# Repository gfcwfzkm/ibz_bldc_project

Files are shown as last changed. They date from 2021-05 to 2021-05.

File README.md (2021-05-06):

# ibz_bldc_project
A group project I participated in during my time in the IBZ side school. The task was any electronic project, so three other fellow students and I decided to build a BLDC driver.
I took care of the schematic, components and layout, another one handled assembly & basic testing, one did the programming / controlling and the last documented the whole project.
This project is not maintained but more a rough reference if anyone else wants to build something similar.
It uses the L6234 as BLDC driver and offers either HALL-Sensor Input or Back-EMF (selectable via jumpers) as well as enough test points to probe on. It was laid out to be a rather flexible but basic platform to explore BLDC Motor driving a bit more.

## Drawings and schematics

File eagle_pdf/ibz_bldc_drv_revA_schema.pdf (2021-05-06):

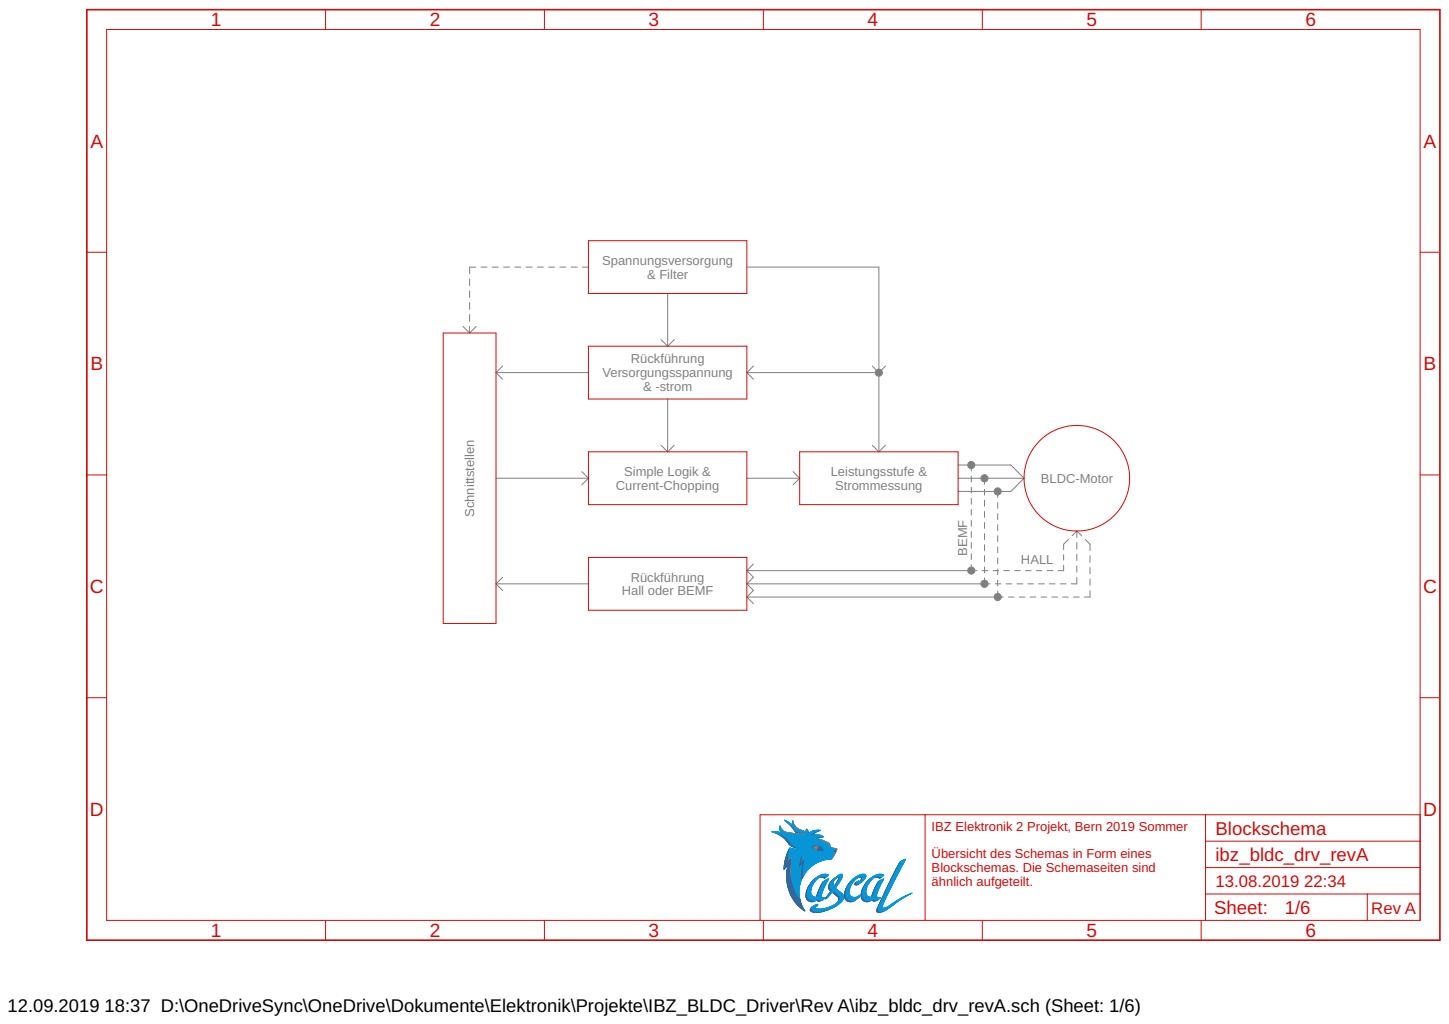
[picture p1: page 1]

IBZ Elektronik 2 Projekt, Bern 2019 Sommer Übersicht des Schemas in Form eines Blockschemas. Die Schemaseiten sind

12.09.2019 18:37 D:\OneDriveSync\OneDrive\Dokumente\Elektronik\Projekte\IBZ_BLDC_Driver\Rev A\ibz_bldc_drv_revA.sch (Sheet: 1/6)

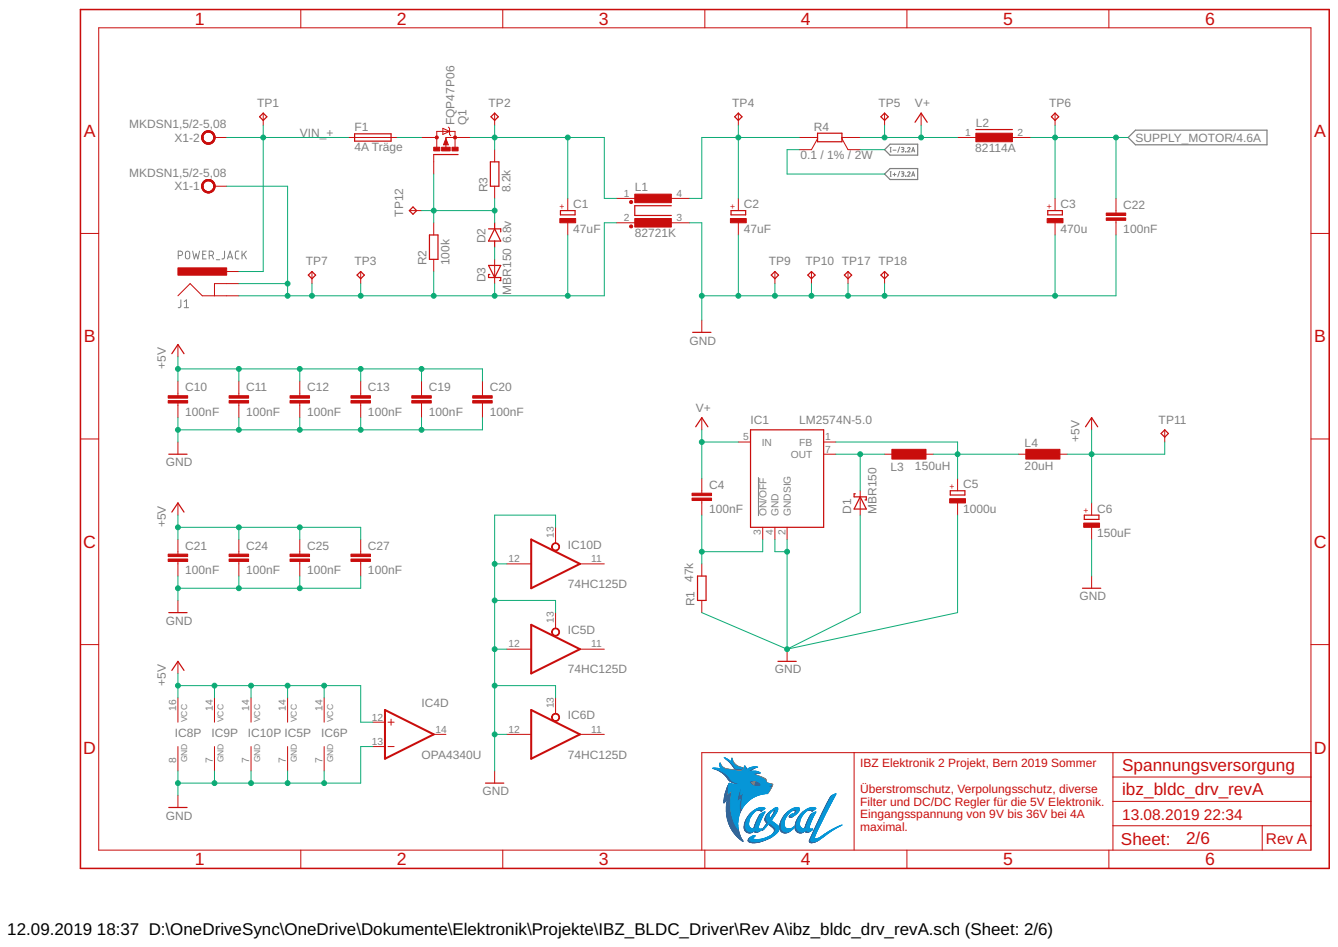
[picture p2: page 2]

12.09.2019 18:37 D:\OneDriveSync\OneDrive\Dokumente\Elektronik\Projekte\IBZ_BLDC_Driver\Rev A\ibz_bldc_drv_revA.sch (Sheet: 2/6)

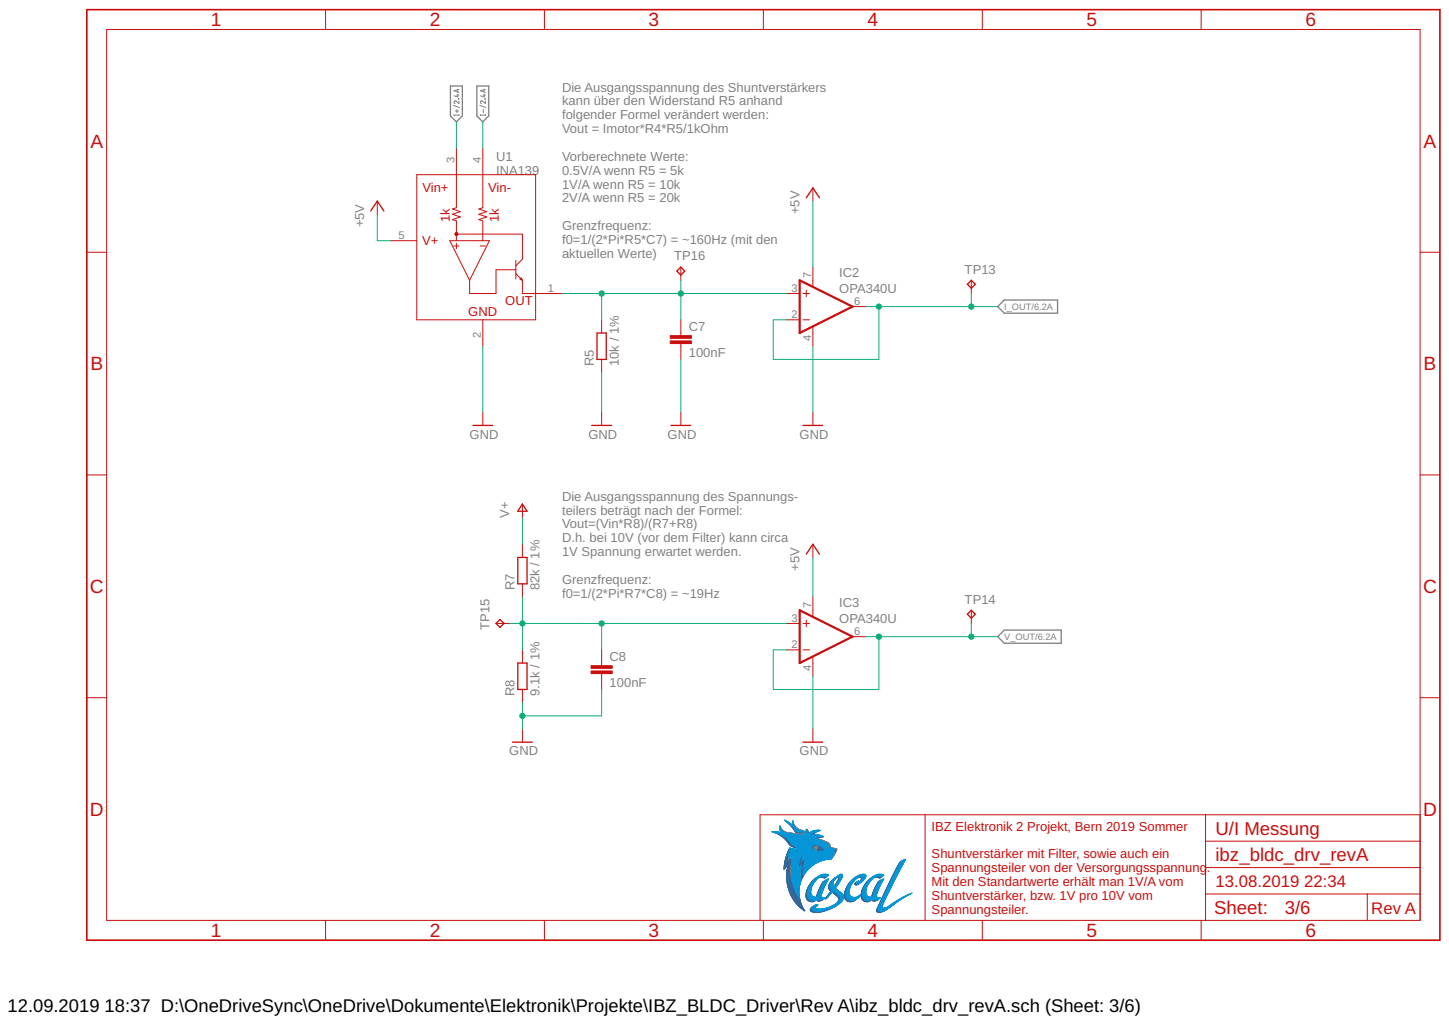
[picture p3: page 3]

Die Ausgangsspannung des Shuntverstärkers
kann über den Widerstand R5 anhand
folgender Formel verändert werden: Vout = Imotor*R4*R5/1kOhm

Die Ausgangsspannung des Spannungs-
teilers beträgt nach der Formel: Vout=(Vin*R8)/(R7+R8)

D.h. bei 10V (vor dem Filter) kann circa
1V Spannung erwartet werden. Grenzfrequenz:

IBZ Elektronik 2 Projekt, Bern 2019 Sommer Shuntverstärker mit Filter, sowie auch ein Spannungsteiler von der Versorgungsspannung. Mit den Standartwerte erhält man 1V/A vom

Shuntverstärker, bzw. 1V pro 10V vom

12.09.2019 18:37 D:\OneDriveSync\OneDrive\Dokumente\Elektronik\Projekte\IBZ_BLDC_Driver\Rev A\ibz_bldc_drv_revA.sch (Sheet: 3/6)

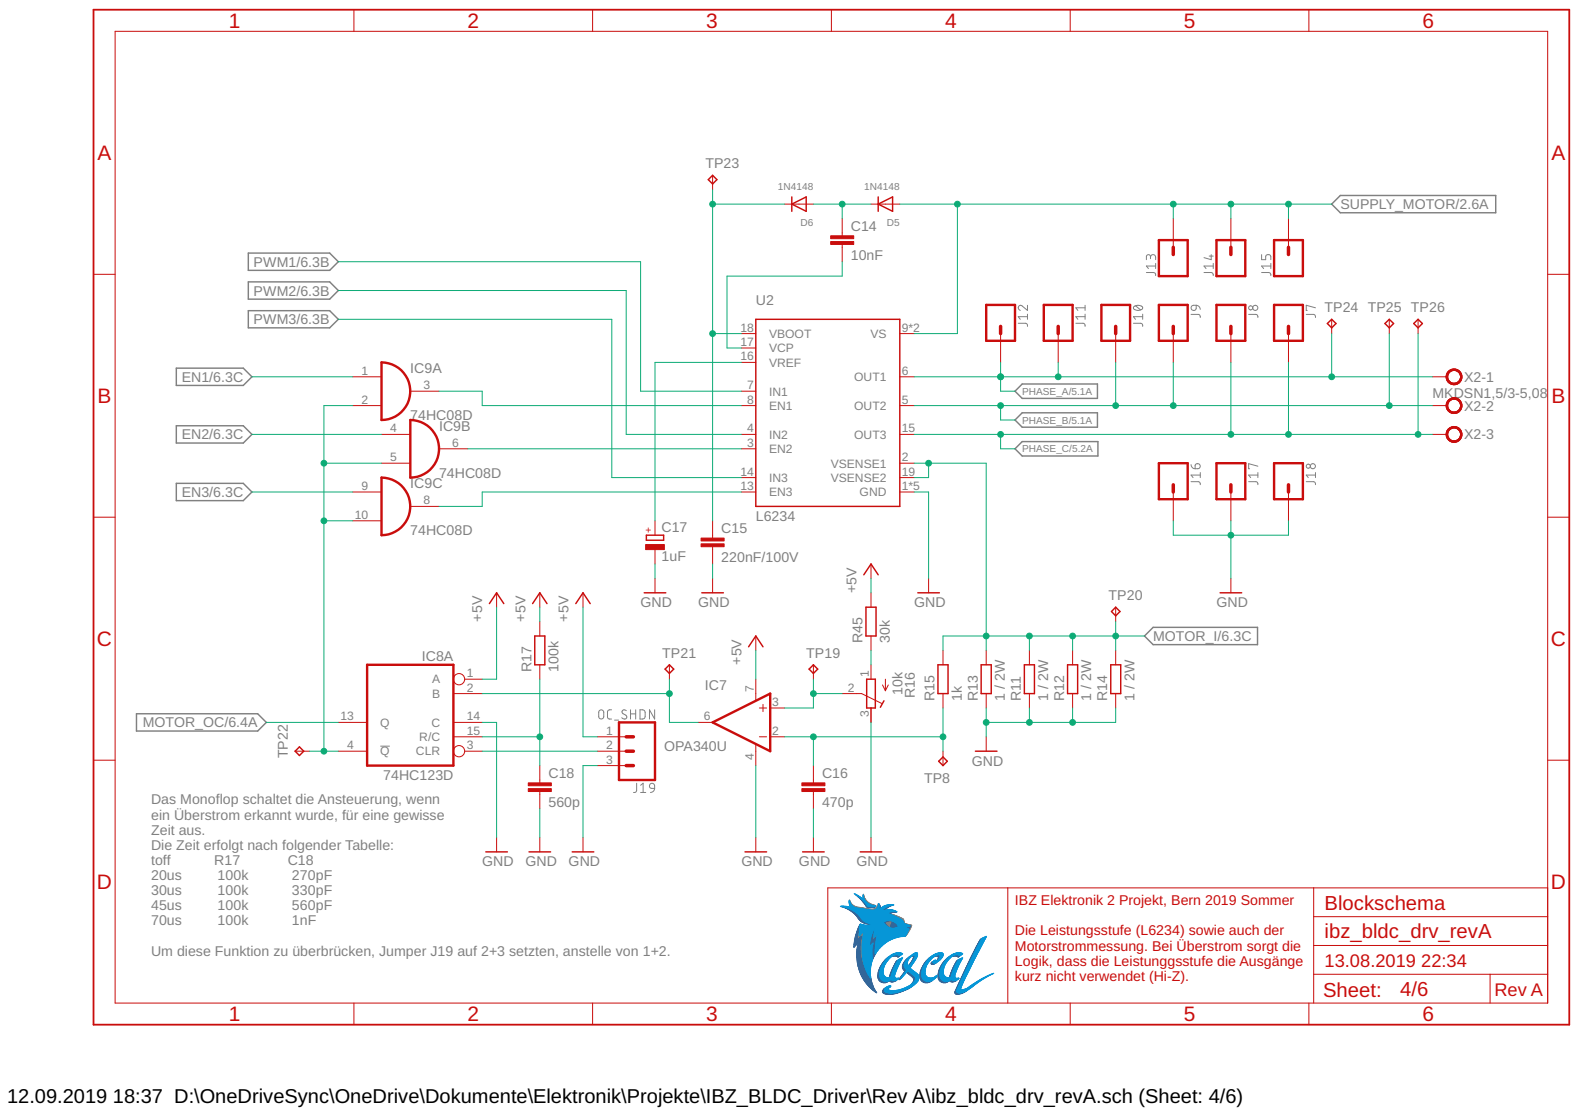
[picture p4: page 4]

Das Monoflop schaltet die Ansteuerung, wenn
ein Überstrom erkannt wurde, für eine gewisse Zeit aus. Die Zeit erfolgt nach folgender Tabelle:

IBZ Elektronik 2 Projekt, Bern 2019 Sommer Die Leistungsstufe (L6234) sowie auch der Motorstrommessung. Bei Überstrom sorgt die

Um diese Funktion zu überbrücken, Jumper J19 auf 2+3 setzten, anstelle von 1+2.

Logik, dass die Leistunggsstufe die Ausgänge

12.09.2019 18:37 D:\OneDriveSync\OneDrive\Dokumente\Elektronik\Projekte\IBZ_BLDC_Driver\Rev A\ibz_bldc_drv_revA.sch (Sheet: 4/6)

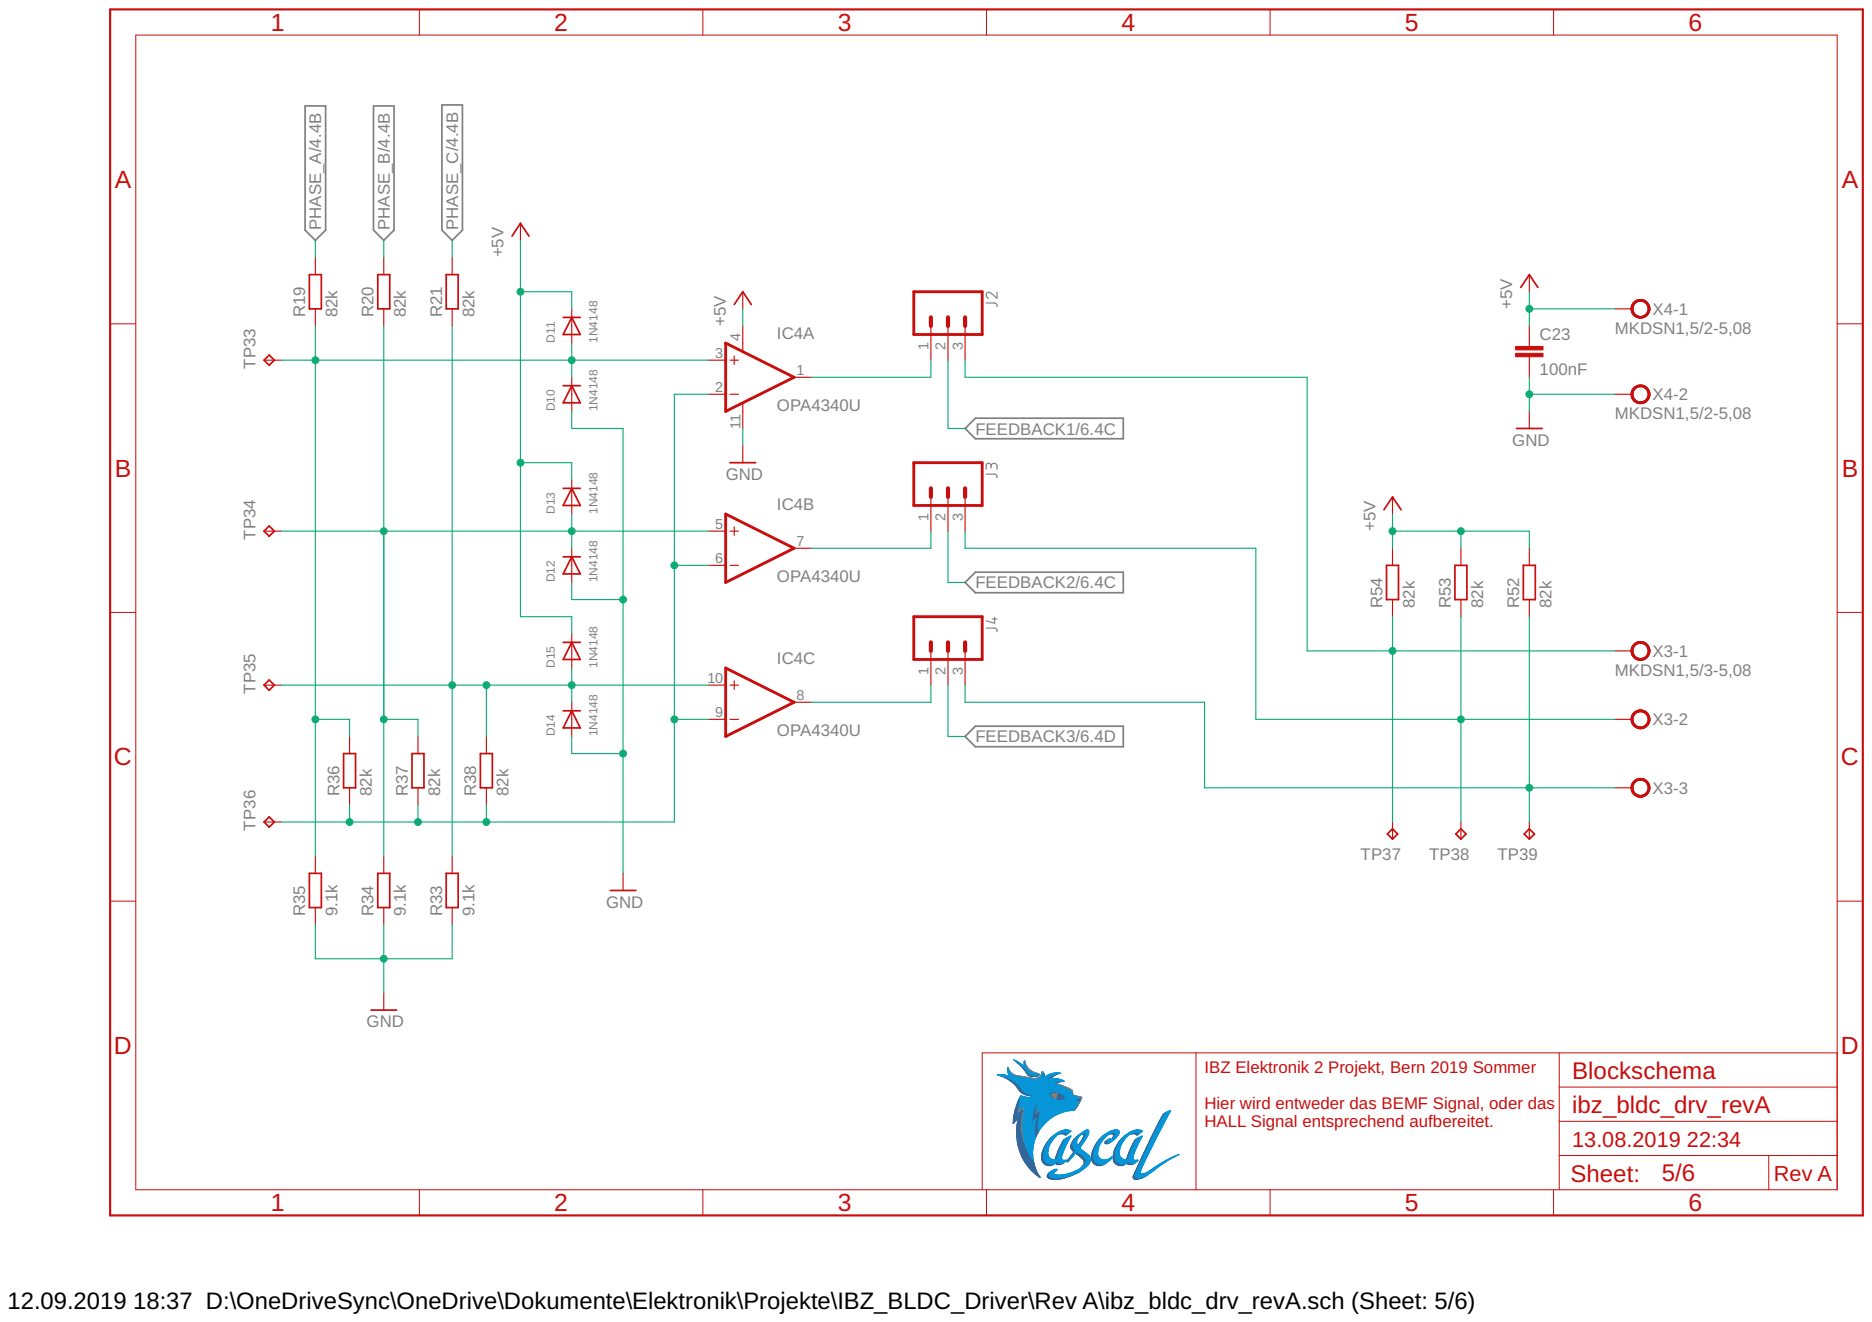
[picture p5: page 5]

12.09.2019 18:37 D:\OneDriveSync\OneDrive\Dokumente\Elektronik\Projekte\IBZ_BLDC_Driver\Rev A\ibz_bldc_drv_revA.sch (Sheet: 5/6)

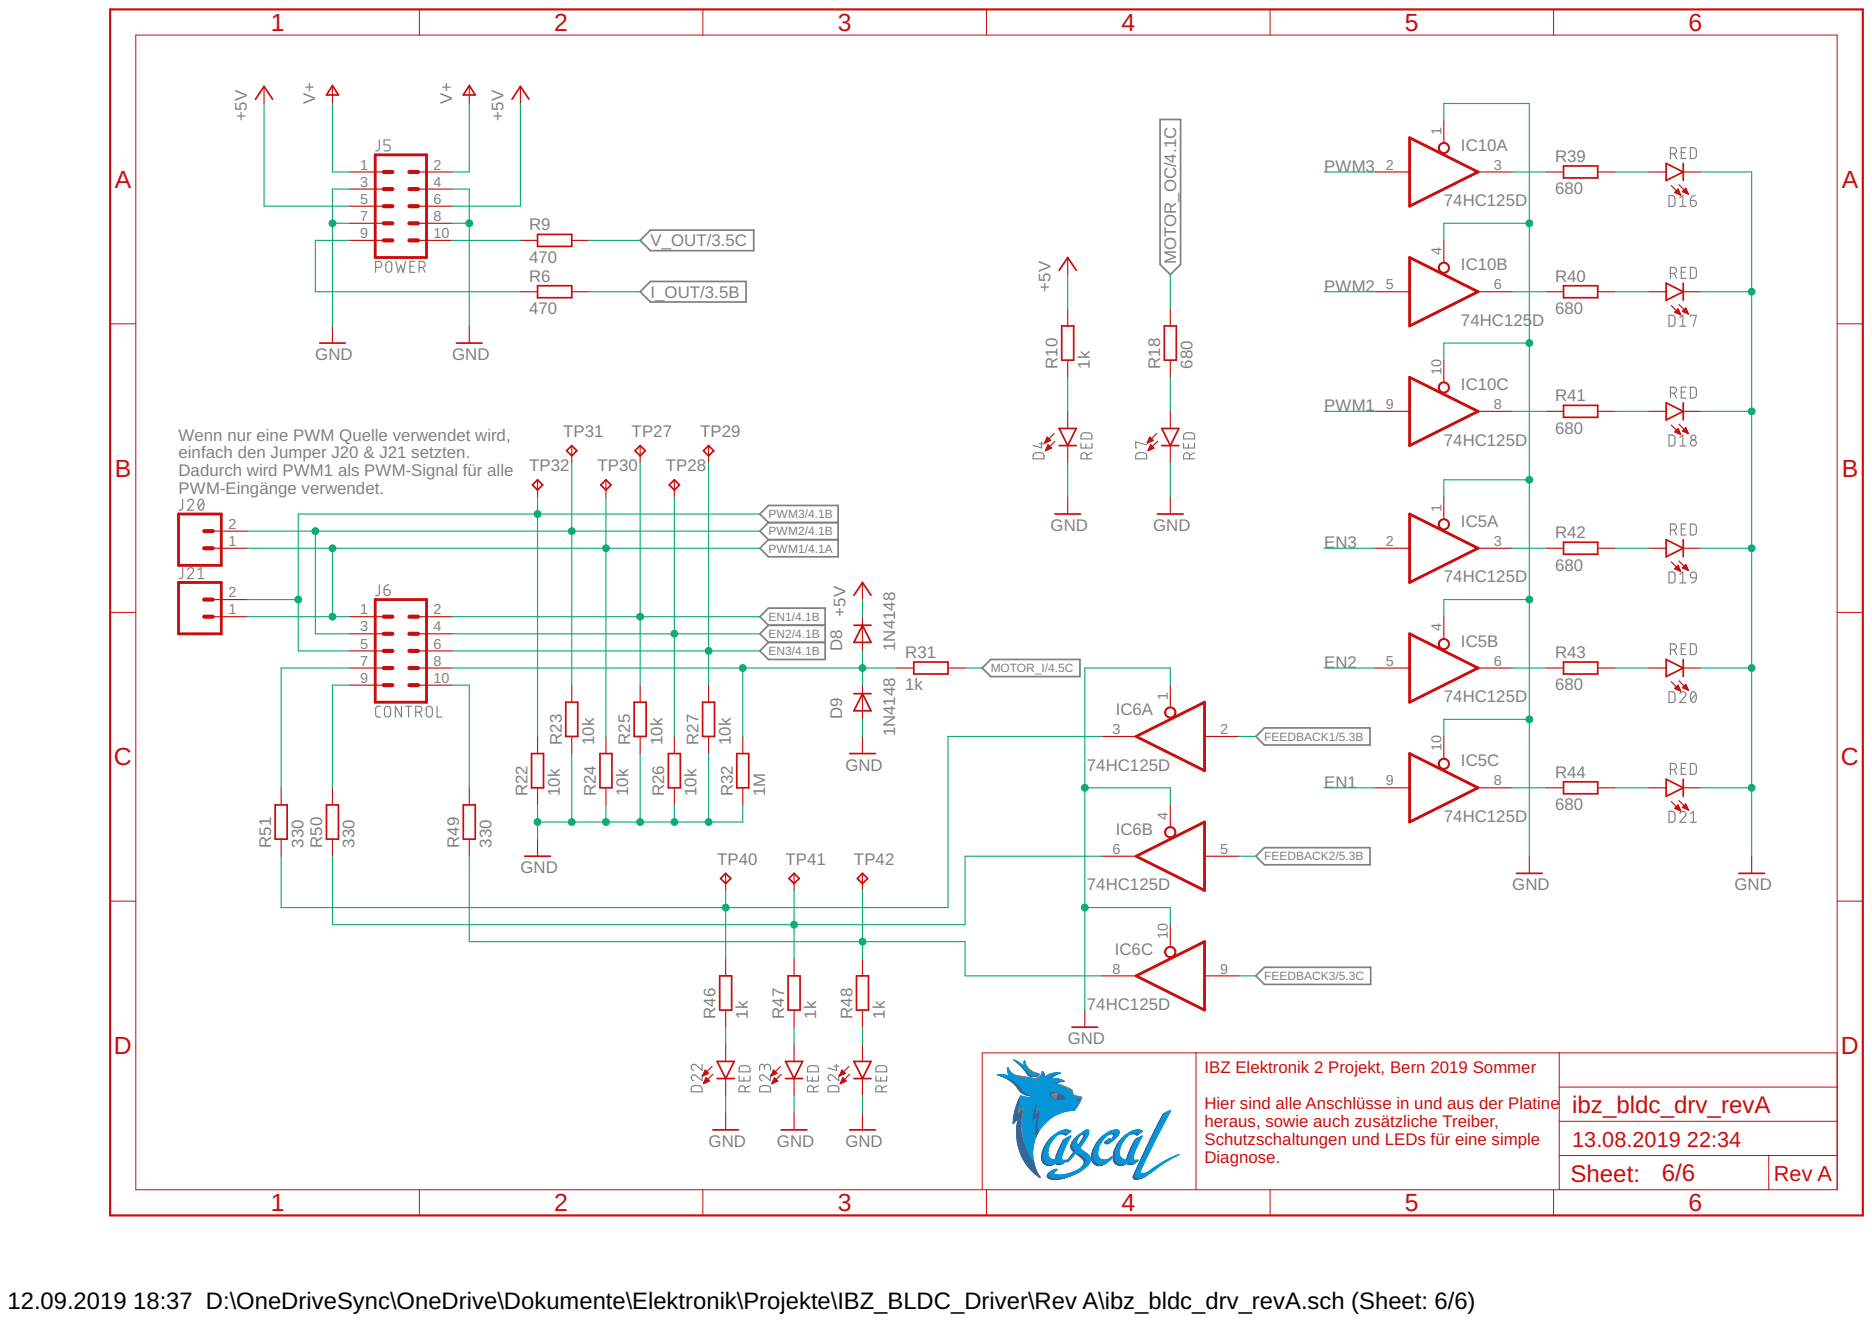
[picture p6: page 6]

Wenn nur eine PWM Quelle verwendet wird, einfach den Jumper J20 & J21 setzten. Dadurch wird PWM1 als PWM-Signal für alle PWM-Eingänge verwendet.

10

IBZ Elektronik 2 Projekt, Bern 2019 Sommer Hier sind alle Anschlüsse in und aus der Platine

12.09.2019 18:37 D:\OneDriveSync\OneDrive\Dokumente\Elektronik\Projekte\IBZ_BLDC_Driver\Rev A\ibz_bldc_drv_revA.sch (Sheet: 6/6)

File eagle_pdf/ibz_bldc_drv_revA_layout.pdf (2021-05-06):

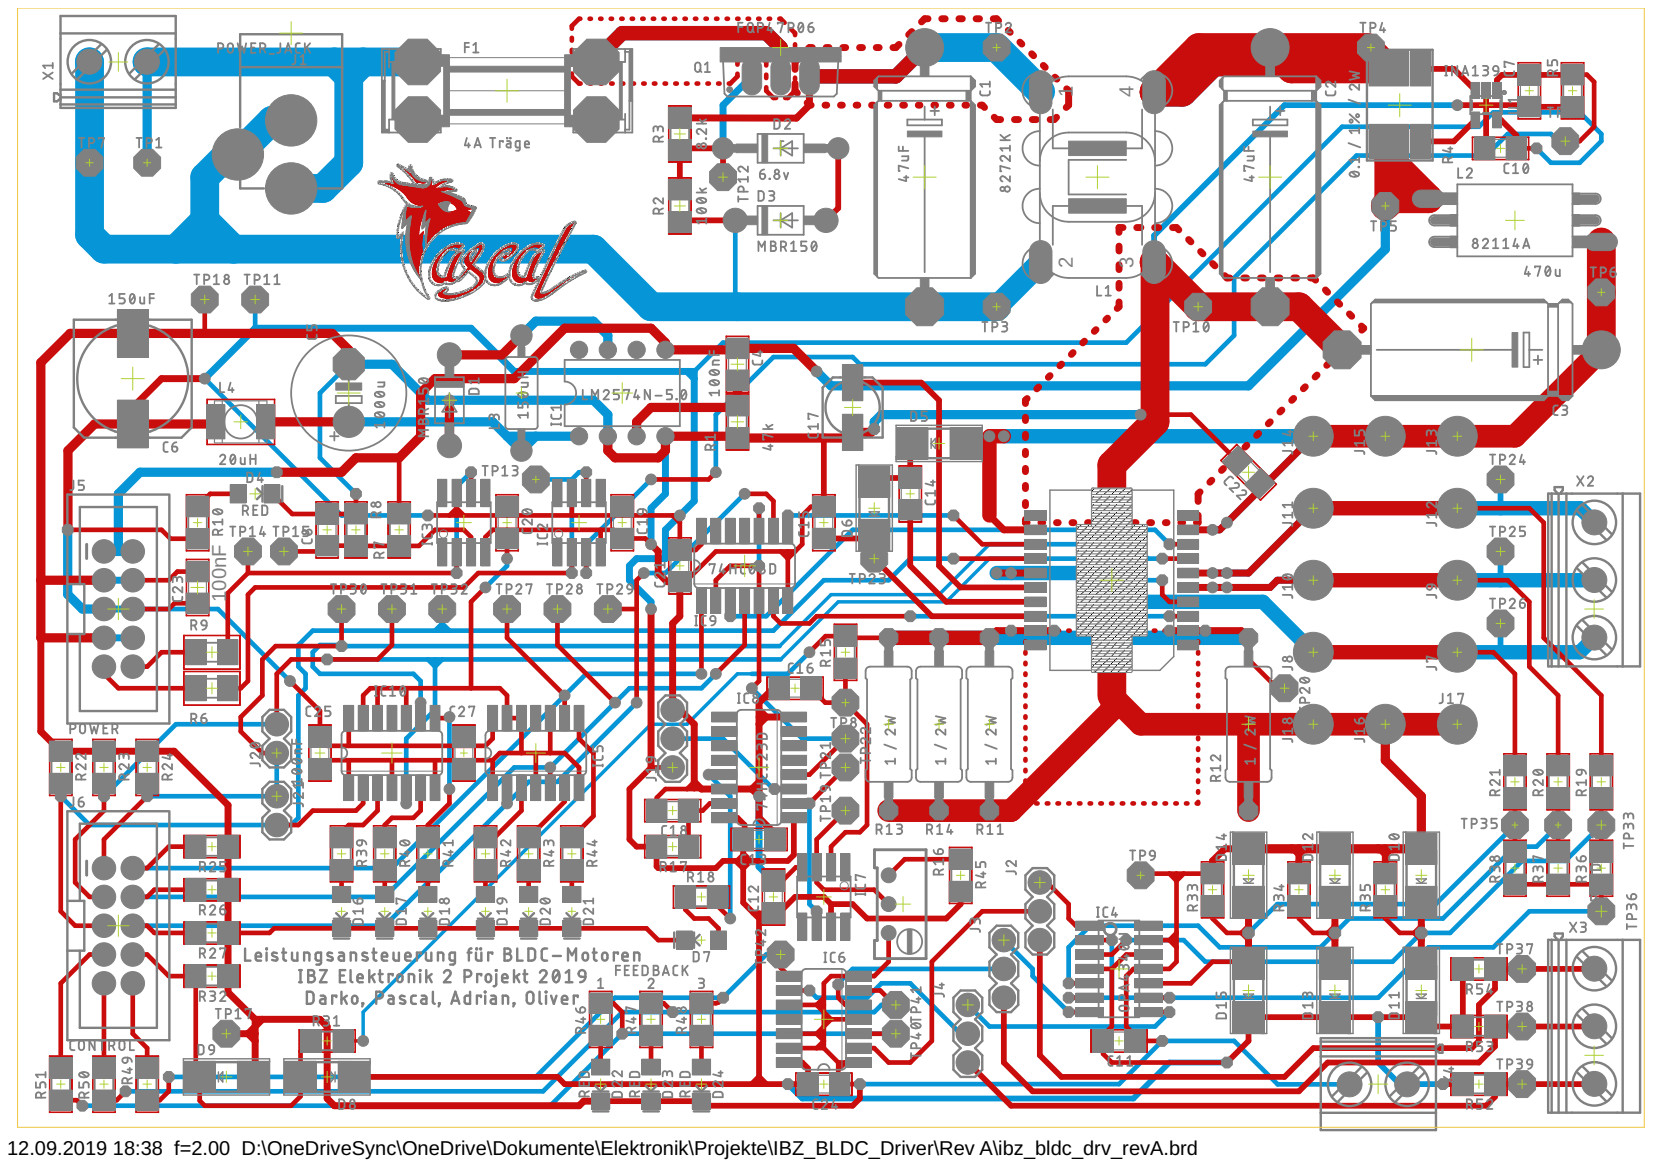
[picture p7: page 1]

12.09.2019 18:38 f=2.00 D:\OneDriveSync\OneDrive\Dokumente\Elektronik\Projekte\IBZ_BLDC_Driver\Rev A\ibz_bldc_drv_revA.brd

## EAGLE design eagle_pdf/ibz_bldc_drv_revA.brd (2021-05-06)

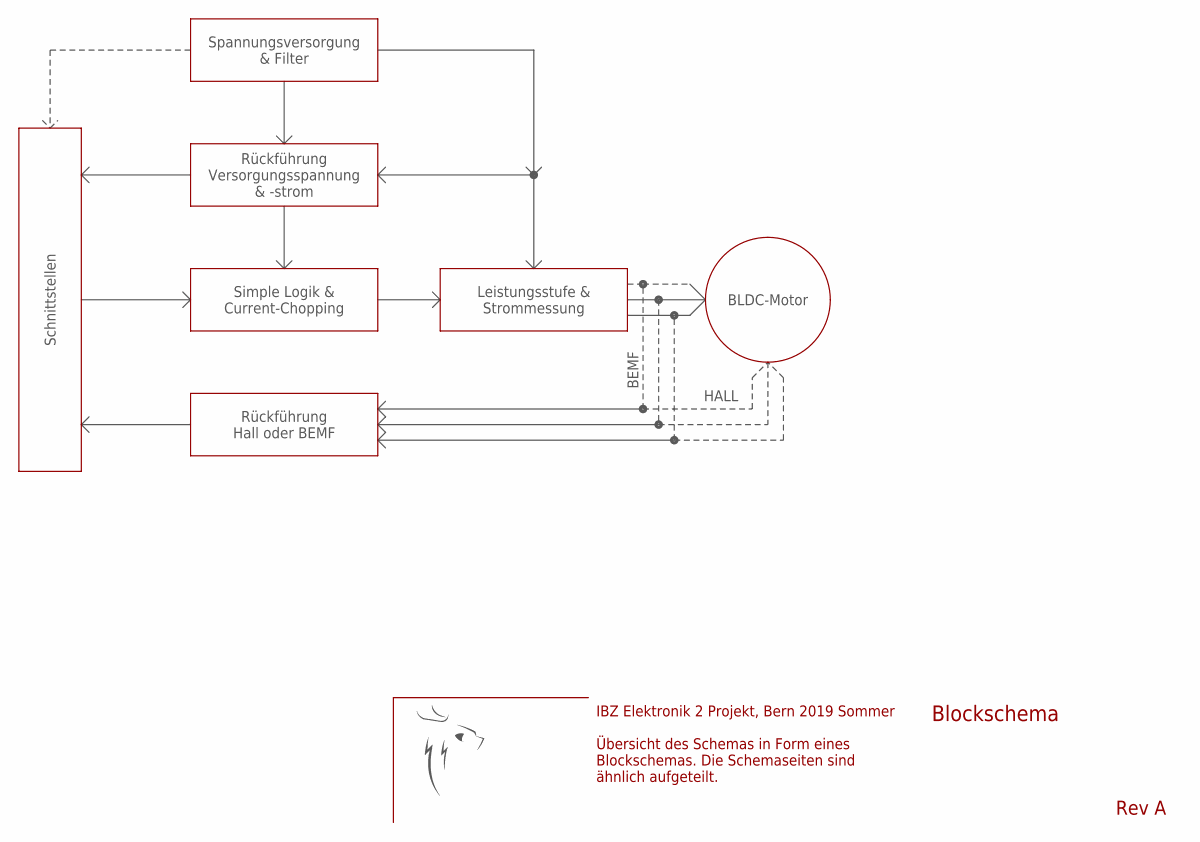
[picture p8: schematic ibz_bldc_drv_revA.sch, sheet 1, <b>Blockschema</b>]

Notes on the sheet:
Spannungsversorgung & Filter
BLDC-Motor
Leistungsstufe & Strommessung
Simple Logik & Current-Chopping
Schnittstellen
Rückführung Versorgungsspannung & -strom
Rückführung Hall oder BEMF
BEMF
HALL
Blockschema
Rev A
IBZ Elektronik 2 Projekt, Bern 2019 Sommer Übersicht des Schemas in Form eines Blockschemas. Die Schemaseiten sind ähnlich aufgeteilt.

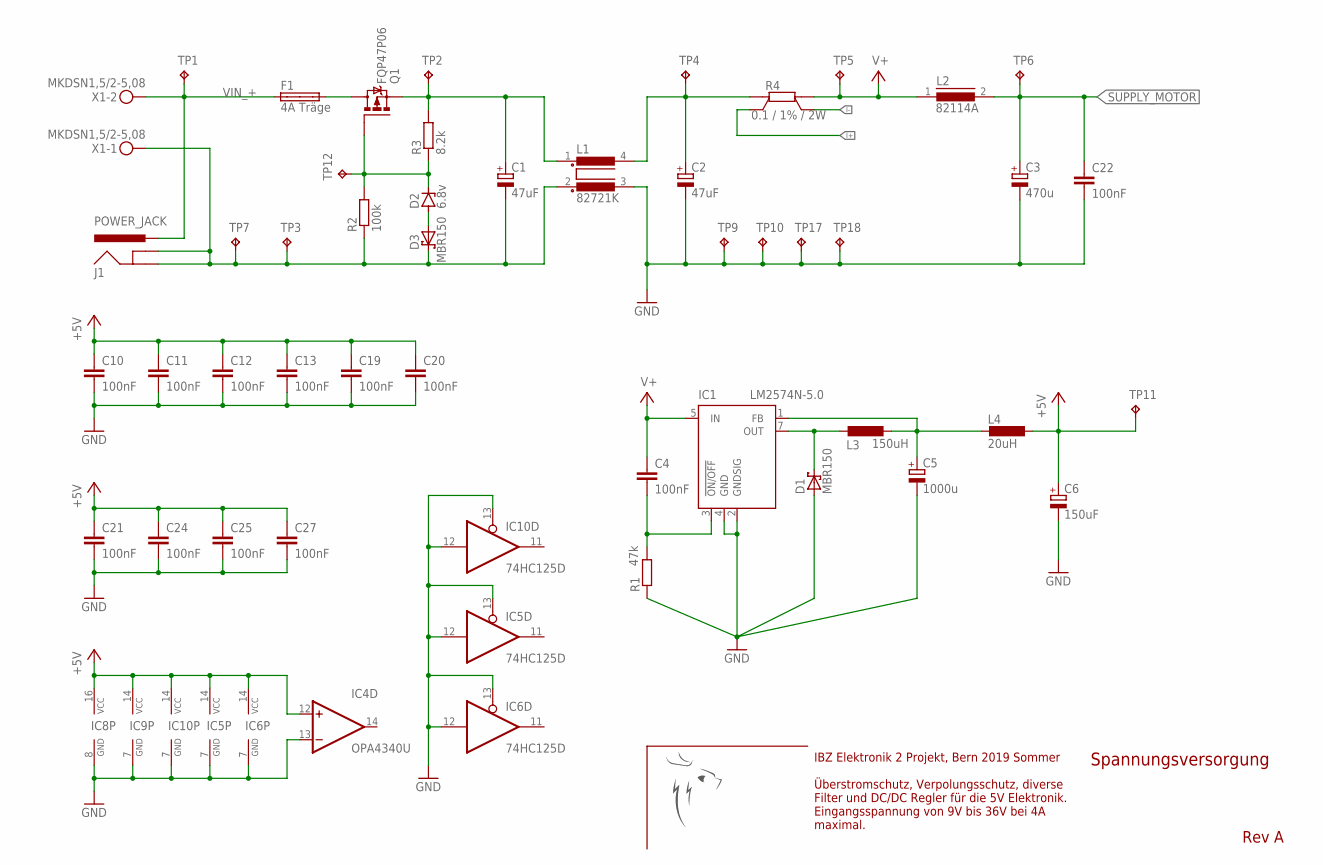
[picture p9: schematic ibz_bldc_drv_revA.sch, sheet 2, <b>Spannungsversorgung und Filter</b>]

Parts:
C1, C2: 47uF; E22-9
C3: 470u; E22-9
C4, C10, C11, C12, C13, C19, C20, C21, C22, C24, C25, C27: 100nF; C1206
C5: 1000u; E5-10,5
C6: 150uF; 153CLV-1010
D1, D3: MBR150; DO41-7
D2: 6.8v; DO41Z10
F1: 4A Träge; SHK20Q
IC1: LM2574N-5.0; DIL08
IC4: OPA4340U; SO14
IC5, IC6, IC10: 74HC125D; SO14
IC8: 74HC123D; SO16
IC9: 74HC08D; SO14
J1: POWER_JACK; POWER_JACK_PTH
L1: 82721K
L2: 82114A
L3: 150uH; IR-2
L4: 20uH; L5038P
Q1: FQP47P06; TO220BV
R1: 47k; R1206
R2: 100k; R1206
R3: 8.2k; R1206
R4: 0.1 / 1% / 2W; PMA-B
TP1, TP2, TP3, TP4, TP5, TP6, TP7, TP9, TP10, TP11, TP12, TP17, TP18: TPPAD1-13; P1-13
X1: MKDSN1,5/2-5,08

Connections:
+5V: C6.+, C10.1, C11.1, C12.1, C13.1, C19.1, C20.1, C21.1, C24.1, C25.1, C27.1, IC4.12 (+IN), IC5.14 (VCC), IC6.14 (VCC), IC8.16 (VCC), IC9.14 (VCC), IC10.14 (VCC), L4.1, TP11.TP; also elsewhere on the board
GND: C2.-, C3.-, C5.-, C6.-, C10.2, C11.2, C12.2, C13.2, C19.2, C20.2, C21.2, C22.2, C24.2, C25.2, C27.2, D1.A, IC1.2 (GNDSIG), IC1.4 (GND), IC4.13 (-IN), IC5.7 (GND), IC5.12 (I), IC5.13 (OE), IC6.7 (GND), IC6.12 (I), IC6.13 (OE), IC8.8 (GND), IC9.7 (GND), IC10.7 (GND), IC10.12 (I), IC10.13 (OE), L1.3 (4), R1.1, TP9.TP, TP10.TP, TP17.TP, TP18.TP; also elsewhere on the board
I+: R4.SB; also elsewhere on the board
I-: R4.SA; also elsewhere on the board
unnamed: C1.-, D3.C, J1.GND, J1.GNDBREAK, L1.2 (3), R2.1, TP3.TP, TP7.TP, X1.1
unnamed: C1.+, L1.1, Q1.S, R3.2, TP2.TP
unnamed: C2.+, L1.4 (2), R4.B, TP4.TP
unnamed: C4.2, IC1.3 (!ON/OFF), R1.2
unnamed: C5.+, IC1.1 (FB), L3.1, L4.2
unnamed: D1.C, IC1.7 (OUT), L3.2
unnamed: F1.2A, Q1.D
unnamed: D2.C, Q1.G, R2.2, R3.1, TP12.TP
unnamed: D2.A, D3.A
SUPPLY_MOTOR: C3.+, C22.1, L2.2, TP6.TP; also elsewhere on the board
V+: C4.1, IC1.5 (IN), L2.1, R4.A, TP5.TP; also elsewhere on the board
VIN_+: F1.1A, J1.PWR, TP1.TP, X1.2

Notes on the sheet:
IBZ Elektronik 2 Projekt, Bern 2019 Sommer Überstromschutz, Verpolungsschutz, diverse Filter und DC/DC Regler für die 5V Elektronik. Eingangsspannung von 9V bis 36V bei 4A maximal.
Spannungsversorgung
Rev A

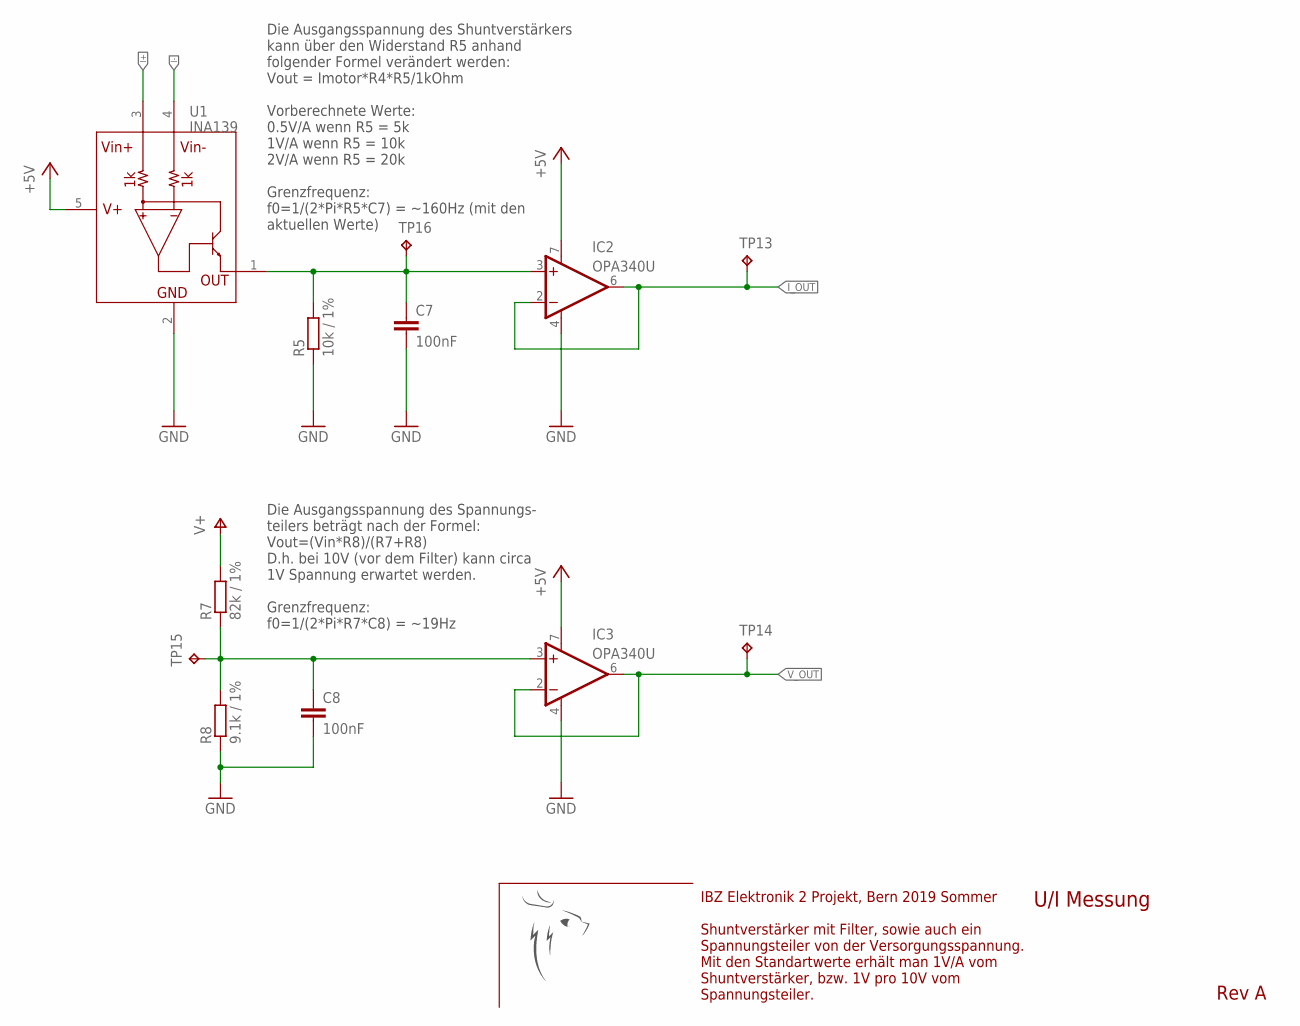
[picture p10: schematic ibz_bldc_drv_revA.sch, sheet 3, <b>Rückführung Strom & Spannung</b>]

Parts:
C7, C8: 100nF; C1206
IC2, IC3: OPA340U; SO08
R5: 10k / 1%; R1206
R7: 82k / 1%; R1206
R8: 9.1k / 1%; R1206
TP13, TP14, TP15, TP16: TPPAD1-13; P1-13
U1: INA139; SOT23-5

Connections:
+5V: IC2.7 (V+), IC3.7 (V+), U1.5 (V+); also elsewhere on the board
GND: C7.2, C8.2, IC2.4 (V-), IC3.4 (V-), R5.1, R8.1, U1.2 (GND); also elsewhere on the board
I+: U1.3 (VIN+); also elsewhere on the board
I-: U1.4 (VIN-); also elsewhere on the board
I_OUT: IC2.2 (-IN), IC2.6 (OUT), TP13.TP; also elsewhere on the board
unnamed: C7.1, IC2.3 (+IN), R5.2, TP16.TP, U1.1 (OUT)
unnamed: C8.1, IC3.3 (+IN), R7.1, R8.2, TP15.TP
V+: R7.2; also elsewhere on the board
V_OUT: IC3.2 (-IN), IC3.6 (OUT), TP14.TP; also elsewhere on the board

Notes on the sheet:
Die Ausgangsspannung des Shuntverstärkers kann über den Widerstand R5 anhand folgender Formel verändert werden: Vout = Imotor*R4*R5/1kOhm Vorberechnete Werte: 0.5V/A wenn R5 = 5k 1V/A wenn R5 = 10k 2V/A wenn R5 = 20k Grenzfrequenz: f0=1/(2*Pi*R5*C7) = ~160Hz (mit den aktuellen Werte)
Die Ausgangsspannung des Spannungs- teilers beträgt nach der Formel: Vout=(Vin*R8)/(R7+R8) D.h. bei 10V (vor dem Filter) kann circa 1V Spannung erwartet werden. Grenzfrequenz: f0=1/(2*Pi*R7*C8) = ~19Hz
IBZ Elektronik 2 Projekt, Bern 2019 Sommer Shuntverstärker mit Filter, sowie auch ein Spannungsteiler von der Versorgungsspannung. Mit den Standartwerte erhält man 1V/A vom Shuntverstärker, bzw. 1V pro 10V vom Spannungsteiler.
U/I Messung
Rev A

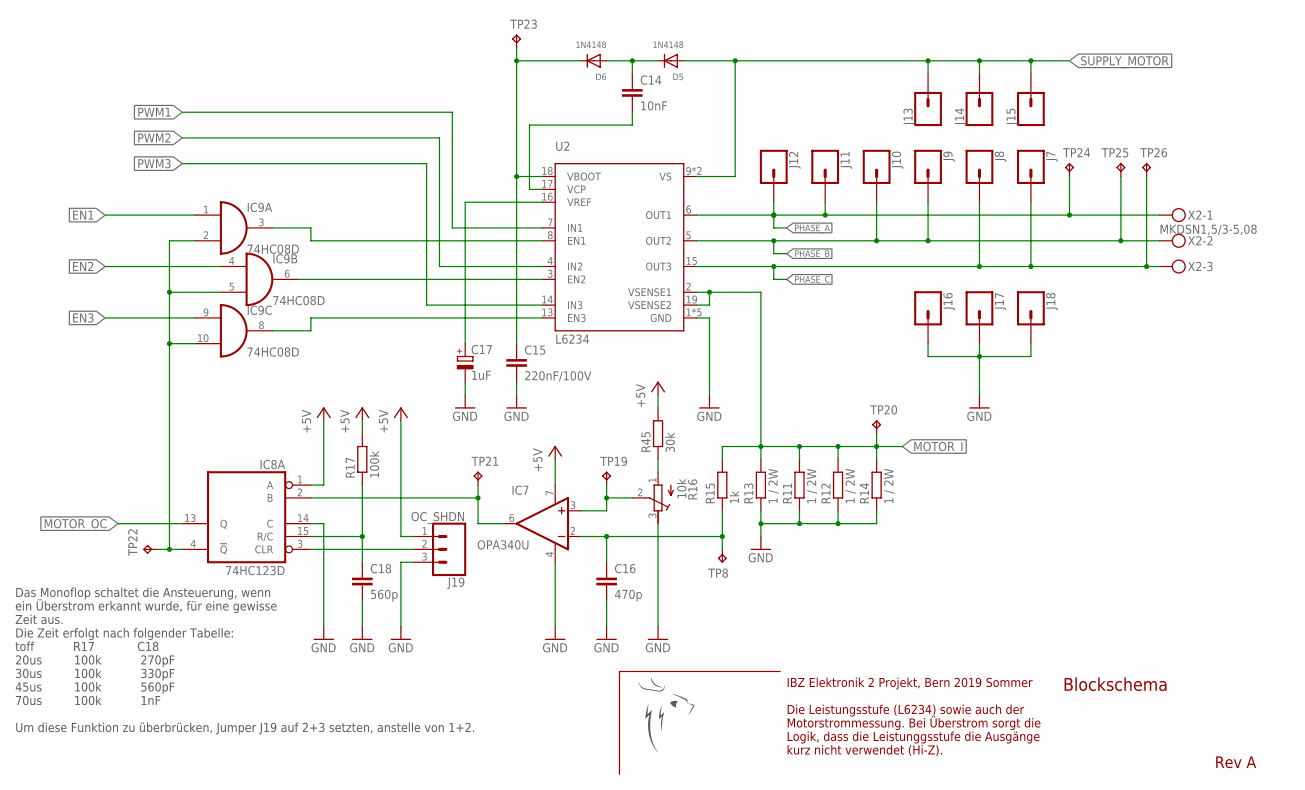
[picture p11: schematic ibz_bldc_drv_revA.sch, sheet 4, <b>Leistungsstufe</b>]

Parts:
C14: 10nF; C1206
C15: 220nF/100V; C1206
C16: 470p; C1206
C17: 1uF; 153CLV-0505
C18: 560p; C1206
D5, D6: 1N4148; SMADIODE
IC7: OPA340U; SO08
IC8: 74HC123D; SO16
IC9: 74HC08D; SO14
J7, J8, J9, J10, J11, J12, J13, J14, J15, J16, J17, J18: CONN_01PTH_2MM; 1X01_2MM
J19: OC_SHDN; 1X03
R11, R12, R13, R14: 1 / 2W; 0411/15
R15: 1k; R1206
R16: 10k; RTRIM64W
R17: 100k; R1206
R45: 30k; R1206
TP8, TP19, TP20, TP21, TP22, TP23, TP24, TP25, TP26: TPPAD1-13; P1-13
U2: L6234; POWERSO20
X2: MKDSN1,5/3-5,08

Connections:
+5V: IC7.7 (V+), IC8.1 (A), J19.1, R17.2, R45.2; also elsewhere on the board
EN1: IC9.1 (I0); also elsewhere on the board
EN2: IC9.4 (I0); also elsewhere on the board
EN3: IC9.9 (I0); also elsewhere on the board
GND: C15.2, C16.2, C17.-, C18.2, IC7.4 (V-), IC8.14 (C), J16.1, J17.1, J18.1, J19.3, R11.1, R12.1, R13.1, R14.1, R16.3 (E), U2.1 (GND), U2.10 (GND), U2.11 (GND), U2.20 (GND), U2.PAD (GND); also elsewhere on the board
MOTOR_I: R11.2, R12.2, R13.2, R14.2, R15.2, TP20.TP, U2.2 (VSENSE1), U2.19 (VSENSE2); also elsewhere on the board
MOTOR_OC: IC8.13 (Q); also elsewhere on the board
unnamed: C14.1, D5.C, D6.A
unnamed: IC9.3 (O), U2.8 (EN1)
unnamed: C15.1, D6.C, TP23.TP, U2.18 (VBOOT)
unnamed: C14.2, U2.17 (VCP)
unnamed: C17.+, U2.16 (VREF)
unnamed: IC9.6 (O), U2.3 (EN2)
unnamed: IC9.8 (O), U2.13 (EN3)
unnamed: C16.1, IC7.2 (-IN), R15.1, TP8.TP
unnamed: IC8.4 (!Q), IC9.2 (I1), IC9.5 (I1), IC9.10 (I1), TP22.TP
unnamed: IC7.6 (OUT), IC8.2 (B), TP21.TP
unnamed: C18.1, IC8.15 (R/C), R17.1
unnamed: IC8.3 (CLR), J19.2
unnamed: IC7.3 (+IN), R16.2 (S), TP19.TP
unnamed: R16.1 (A), R45.1
PHASE_A: J11.1, J12.1, TP24.TP, U2.6 (OUT1), X2.1; also elsewhere on the board
PHASE_B: J9.1, J10.1, TP25.TP, U2.5 (OUT2), X2.2; also elsewhere on the board
PHASE_C: J7.1, J8.1, TP26.TP, U2.15 (OUT3), X2.3; also elsewhere on the board
PWM1: U2.7 (IN1); also elsewhere on the board
PWM2: U2.4 (IN2); also elsewhere on the board
PWM3: U2.14 (IN3); also elsewhere on the board
SUPPLY_MOTOR: D5.A, J13.1, J14.1, J15.1, U2.9 (VS), U2.12 (VS); also elsewhere on the board

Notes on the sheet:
IBZ Elektronik 2 Projekt, Bern 2019 Sommer Die Leistungsstufe (L6234) sowie auch der Motorstrommessung. Bei Überstrom sorgt die Logik, dass die Leistunggsstufe die Ausgänge kurz nicht verwendet (Hi-Z).
Blockschema
Rev A
Das Monoflop schaltet die Ansteuerung, wenn ein Überstrom erkannt wurde, für eine gewisse Zeit aus. Die Zeit erfolgt nach folgender Tabelle: toff R17 C18 20us 100k 270pF 30us 100k 330pF 45us 100k 560pF 70us 100k 1nF Um diese Funktion zu überbrücken, Jumper J19 auf 2+3 setzten, anstelle von 1+2.

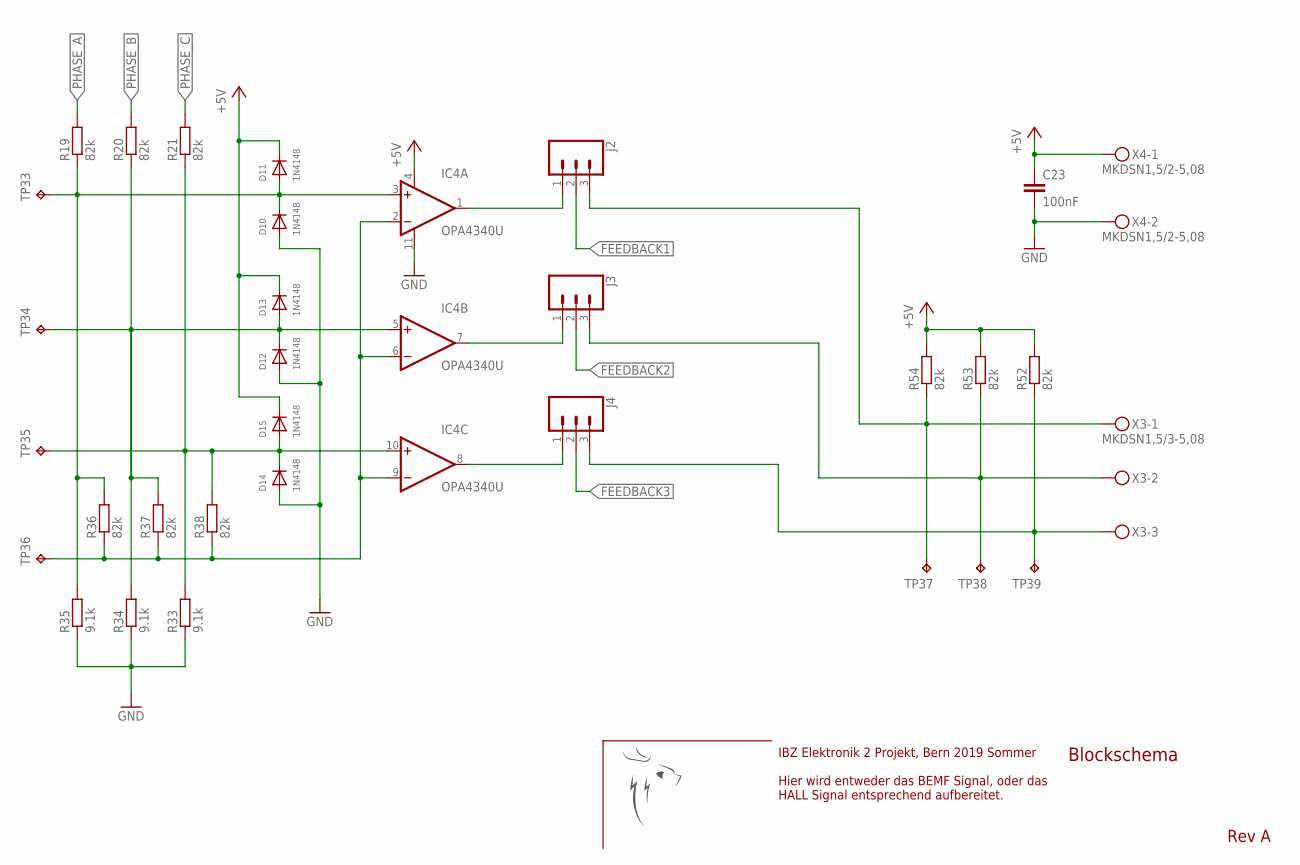
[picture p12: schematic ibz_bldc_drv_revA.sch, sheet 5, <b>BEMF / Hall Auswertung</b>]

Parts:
C23: 100nF; C1206
D10, D11, D12, D13, D14, D15: 1N4148; SMADIODE
IC4: OPA4340U; SO14
J2, J3, J4: CONN_03; 1X03
R19, R20, R21, R36, R37, R38, R52, R53, R54: 82k; R1206
R33, R34, R35: 9.1k; R1206
TP33, TP34, TP35, TP36, TP37, TP38, TP39: TPPAD1-13; P1-13
X3: MKDSN1,5/3-5,08
X4: MKDSN1,5/2-5,08

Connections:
+5V: C23.1, D11.C, D13.C, D15.C, IC4.4 (V+), R52.2, R53.2, R54.2, X4.1; also elsewhere on the board
FEEDBACK1: J2.2; also elsewhere on the board
FEEDBACK2: J3.2; also elsewhere on the board
FEEDBACK3: J4.2; also elsewhere on the board
GND: C23.2, D10.A, D12.A, D14.A, IC4.11 (V-), R33.1, R34.1, R35.1, X4.2; also elsewhere on the board
unnamed: D14.C, D15.A, IC4.10 (+IN), R21.1, R33.2, R38.2, TP35.TP
unnamed: D10.C, D11.A, IC4.3 (+IN), R19.1, R35.2, R36.2, TP33.TP
unnamed: D12.C, D13.A, IC4.5 (+IN), R20.1, R34.2, R37.2, TP34.TP
unnamed: IC4.1 (OUT), J2.1
unnamed: IC4.2 (-IN), IC4.6 (-IN), IC4.9 (-IN), R36.1, R37.1, R38.1, TP36.TP
unnamed: IC4.7 (OUT), J3.1
unnamed: IC4.8 (OUT), J4.1
unnamed: J2.3, R54.1, TP37.TP, X3.1
unnamed: J3.3, R53.1, TP38.TP, X3.2
unnamed: J4.3, R52.1, TP39.TP, X3.3
PHASE_A: R19.2; also elsewhere on the board
PHASE_B: R20.2; also elsewhere on the board
PHASE_C: R21.2; also elsewhere on the board

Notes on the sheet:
IBZ Elektronik 2 Projekt, Bern 2019 Sommer Hier wird entweder das BEMF Signal, oder das HALL Signal entsprechend aufbereitet.
Blockschema
Rev A

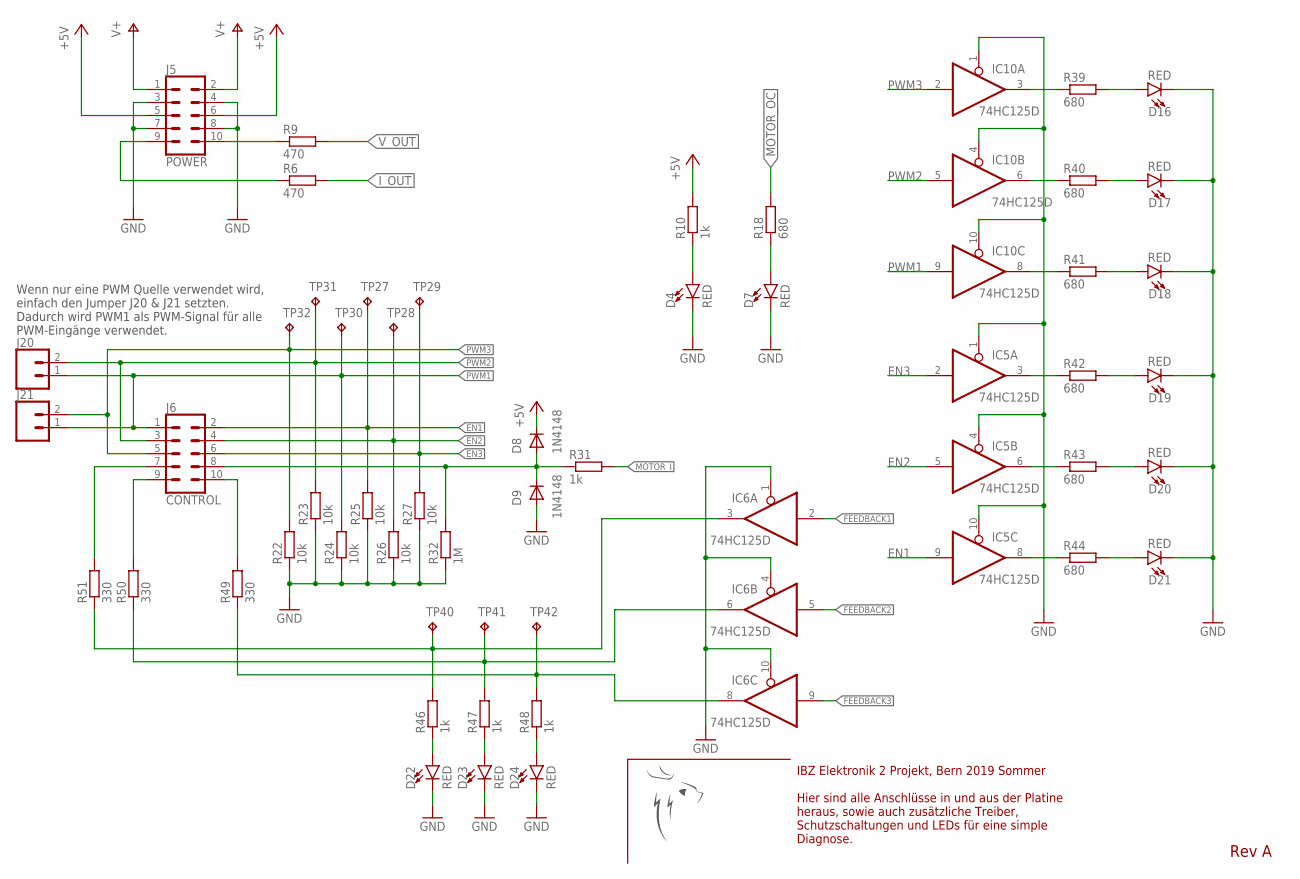
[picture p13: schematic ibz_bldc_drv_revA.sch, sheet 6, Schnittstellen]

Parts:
D4, D7, D16, D17, D18, D19, D20, D21, D22, D23, D24: RED; LED-1206
D8, D9: 1N4148; SMADIODE
IC5, IC6, IC10: 74HC125D; SO14
J5: POWER; 2X5-SHROUDED
J6: CONTROL; 2X5-SHROUDED
J20, J21: CONN_02; 1X02
R6, R9: 470; M1206
R10, R31, R46, R47, R48: 1k; R1206
R18, R39, R40, R41, R42, R43, R44: 680; R1206
R22, R23, R24, R25, R26, R27: 10k; R1206
R32: 1M; R1206
R49, R50, R51: 330; R1206
TP27, TP28, TP29, TP30, TP31, TP32, TP40, TP41, TP42: TPPAD1-13; P1-13

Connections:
+5V: D8.C, J5.5, J5.6, R10.2; also elsewhere on the board
EN1: IC5.9 (I), J6.2, R25.2, TP27.TP; also elsewhere on the board
EN2: IC5.5 (I), J6.4, R26.2, TP28.TP; also elsewhere on the board
EN3: IC5.2 (I), J6.6, R27.2, TP29.TP; also elsewhere on the board
FEEDBACK1: IC6.2 (I); also elsewhere on the board
FEEDBACK2: IC6.5 (I); also elsewhere on the board
FEEDBACK3: IC6.9 (I); also elsewhere on the board
GND: D4.C, D7.C, D9.A, D16.C, D17.C, D18.C, D19.C, D20.C, D21.C, D22.C, D23.C, D24.C, IC5.1 (OE), IC5.4 (OE), IC5.10 (OE), IC6.1 (OE), IC6.4 (OE), IC6.10 (OE), IC10.1 (OE), IC10.4 (OE), IC10.10 (OE), J5.3, J5.4, J5.7, J5.8, R22.1, R23.1, R24.1, R25.1, R26.1, R27.1, R32.1; also elsewhere on the board
I_OUT: R6.2; also elsewhere on the board
MOTOR_I: R31.2; also elsewhere on the board
MOTOR_OC: R18.2; also elsewhere on the board
unnamed: D4.A, R10.1
unnamed: J5.9, R6.1
unnamed: J5.10, R9.1
unnamed: D7.A, R18.1
unnamed: D8.A, D9.C, J6.8, R31.1, R32.2
unnamed: IC10.3 (O), R39.1
unnamed: IC10.6 (O), R40.1
unnamed: IC10.8 (O), R41.1
unnamed: IC5.3 (O), R42.1
unnamed: D19.A, R42.2
unnamed: D18.A, R41.2
unnamed: D17.A, R40.2
unnamed: D16.A, R39.2
unnamed: IC5.6 (O), R43.1
unnamed: D20.A, R43.2
unnamed: IC5.8 (O), R44.1
unnamed: D21.A, R44.2
unnamed: J6.10, R49.2
unnamed: IC6.8 (O), R48.2, R49.1, TP42.TP
unnamed: IC6.6 (O), R47.2, R50.1, TP41.TP
unnamed: IC6.3 (O), R46.2, R51.1, TP40.TP
unnamed: D22.A, R46.1
unnamed: D23.A, R47.1
unnamed: D24.A, R48.1
unnamed: J6.9, R50.2
unnamed: J6.7, R51.2
PWM1: IC10.9 (I), J6.1, J20.1, J21.1, R24.2, TP30.TP; also elsewhere on the board
PWM2: IC10.5 (I), J6.3, J20.2, R23.2, TP31.TP; also elsewhere on the board
PWM3: IC10.2 (I), J6.5, J21.2, R22.2, TP32.TP; also elsewhere on the board
V+: J5.1, J5.2; also elsewhere on the board
V_OUT: R9.2; also elsewhere on the board

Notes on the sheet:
Wenn nur eine PWM Quelle verwendet wird, einfach den Jumper J20 & J21 setzten. Dadurch wird PWM1 als PWM-Signal für alle PWM-Eingänge verwendet.
IBZ Elektronik 2 Projekt, Bern 2019 Sommer Hier sind alle Anschlüsse in und aus der Platine heraus, sowie auch zusätzliche Treiber, Schutzschaltungen und LEDs für eine simple Diagnose.
Rev A

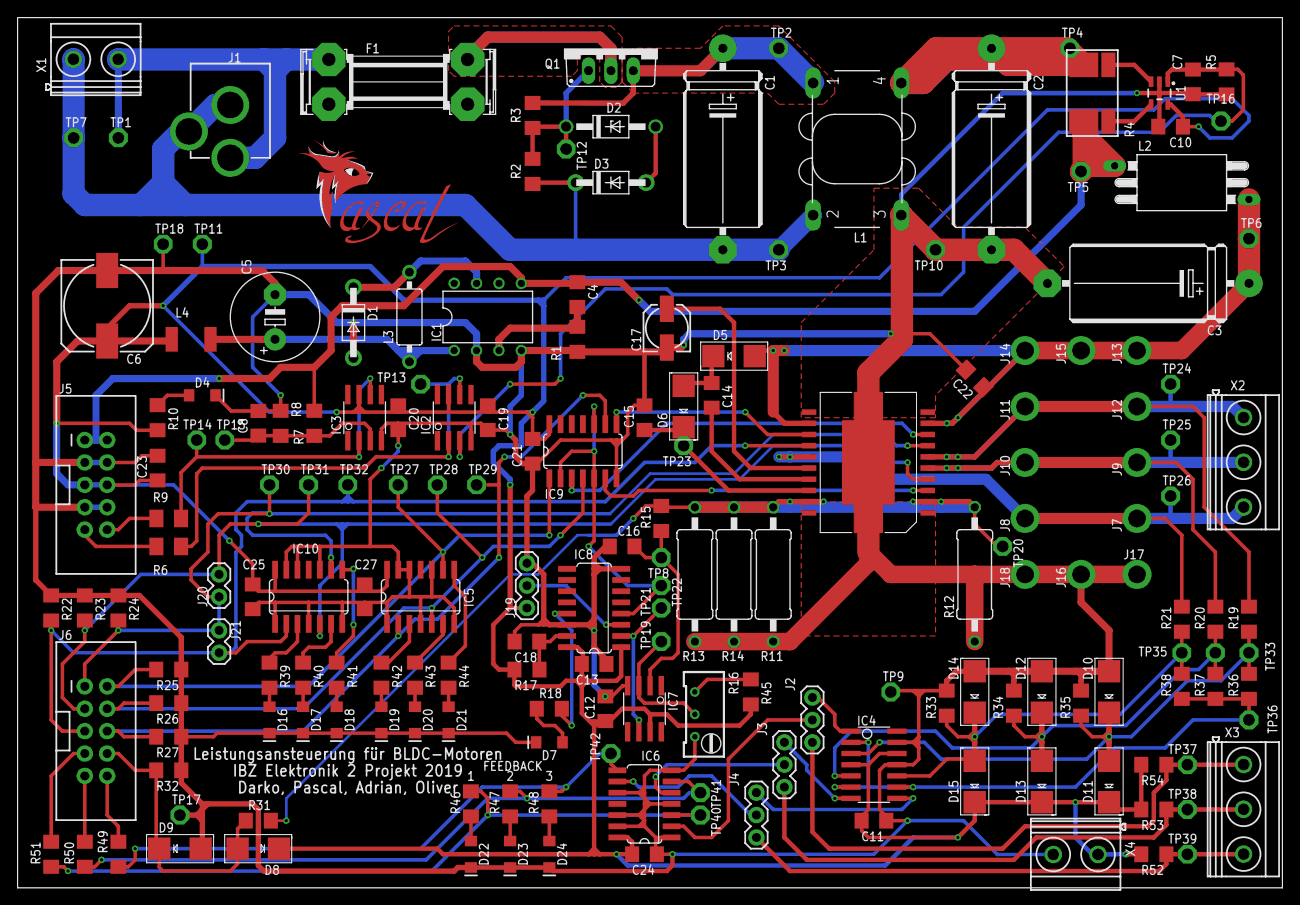
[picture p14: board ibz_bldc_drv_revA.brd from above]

Board: 2 copper layers, 143.5 x 98.7 mm, 185 parts (0 on the bottom side), 84 nets.

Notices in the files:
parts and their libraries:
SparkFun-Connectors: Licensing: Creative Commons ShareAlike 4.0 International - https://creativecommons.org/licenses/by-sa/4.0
